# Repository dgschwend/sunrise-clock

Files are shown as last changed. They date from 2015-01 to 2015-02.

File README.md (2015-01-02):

Sunrise Clock
=============

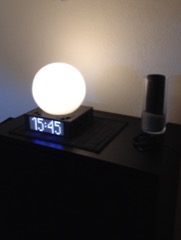
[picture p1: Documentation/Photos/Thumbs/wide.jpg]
Image of Alarm Clock from Wide Angle
[][wide]        
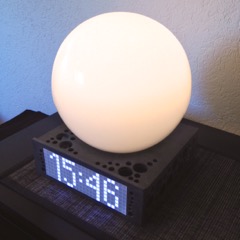
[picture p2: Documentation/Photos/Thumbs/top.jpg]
Image of Top of Alarm Clock
[][top]

A hand-made alarm clock that uses slowly increasing light and sound to wake you up.

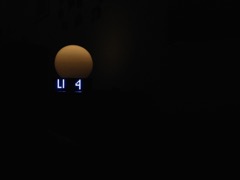
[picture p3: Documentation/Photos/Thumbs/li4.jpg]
[][li4] 
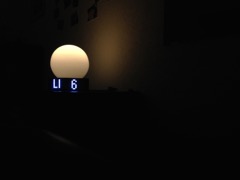
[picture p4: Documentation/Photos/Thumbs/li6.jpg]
[][li6] 
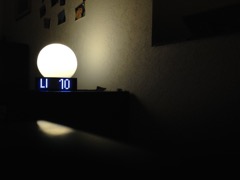
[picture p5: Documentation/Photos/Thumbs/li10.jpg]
Image of Medium Light
[][li10] 
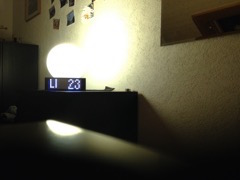
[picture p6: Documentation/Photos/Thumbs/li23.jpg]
Image of Bright Light
[][li23]

## Project Features

Built for an Arduino Pro Mini using the fantastic [Arduino Che Cosa framework](http://github.com/mikaelpatel/Cosa).

  - White LED Matrix Display shows Time and Menus
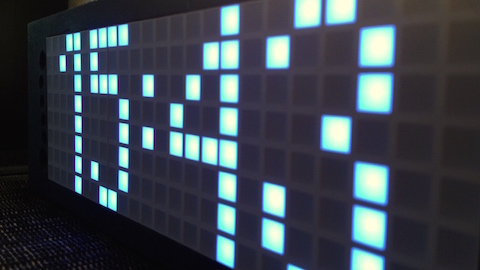
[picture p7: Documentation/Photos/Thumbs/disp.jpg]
Image of Display
   [][disp]    
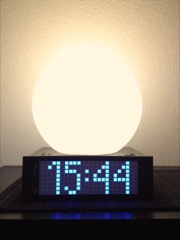
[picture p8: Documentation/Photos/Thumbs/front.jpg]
Image of Front
   [][front]

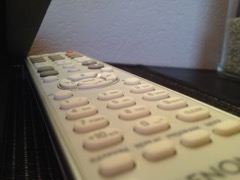
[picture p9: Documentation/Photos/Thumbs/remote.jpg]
Image of IR Remote
  - [][remote]        IR recevier, Apple Remote (or others) for control

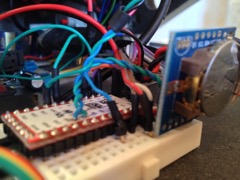
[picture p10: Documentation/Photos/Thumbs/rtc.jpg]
Image of Real-Time Clock
  - [][rtc]        TinyRTC Real-Time Clock (for time and alarms, battery-backup)
  
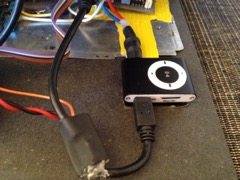
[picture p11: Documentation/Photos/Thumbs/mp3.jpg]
Image of MP3 Player
  - [][mp3]        Cheap chinese MP3 Player for Wakeup Sound

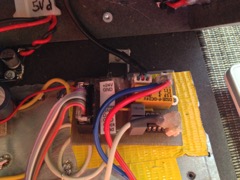
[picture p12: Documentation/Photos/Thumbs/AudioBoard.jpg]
Image of AudioBoard
  - [][AudioBoard]        Audio Volume Control (via LM1972)

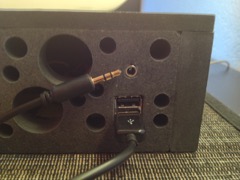
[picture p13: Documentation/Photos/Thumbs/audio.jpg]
Image of Audio AUX Port
  - [][audio]        Audio Switch (external Jack input, internal MP3)

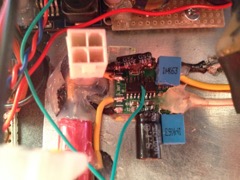
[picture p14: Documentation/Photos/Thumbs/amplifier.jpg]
Image of Amplifier
  - [][amplifier]        2 x 3W Amplifier (PAM8403)

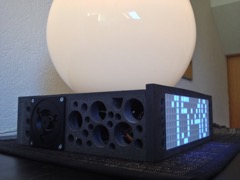
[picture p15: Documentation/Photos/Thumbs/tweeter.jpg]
Image of Tweeter
  - [][tweeter]        2-way Speaker
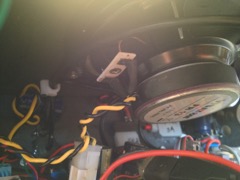
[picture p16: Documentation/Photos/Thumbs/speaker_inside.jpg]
Image of Speaker inside
  - [][speaker_inside]        Subwoofer included in glass sphere
 
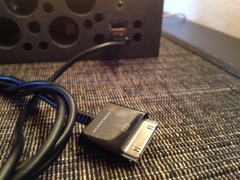
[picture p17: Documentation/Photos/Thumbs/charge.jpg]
Image of Charge Port
  - [][charge]        2x USB Charger 5V @ 1.5A

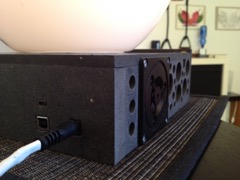
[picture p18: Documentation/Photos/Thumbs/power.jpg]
Image of Power and USB Config Port
  - [][power]        USB Flash / Debug Port <--> FTDI <--> Arduino

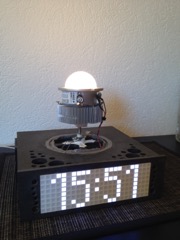
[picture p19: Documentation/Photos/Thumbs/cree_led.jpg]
Image of Cree LMH2 LED
  - [][cree_led]                     Cree LMH2 850-lumen LED with sunset dimming

  - old Apple iBook G4 Power Supply @24.8V, 1.8A for Power

## Under-the-Hood Impressions

### Setup and Cabling
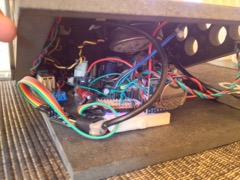
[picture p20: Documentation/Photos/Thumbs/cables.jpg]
Image of Cables
[][cables]
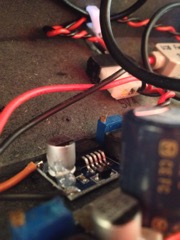
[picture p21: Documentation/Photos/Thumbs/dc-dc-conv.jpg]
Image of DC-DC Converter
[][dc-dc-conv]
[Image of Real-Time Clock][rtc]

DIY PCB for Audio Volume Control. All cabling and setup still in prototype stage. I'm thinking about doing a small PCB for all the components... Audio Quality could certainly be improved with properly shielded 4-layer PCB.

### Audio Hardware
[Image of Amplifier][amplifier]
[Image of AudioBoard][AudioBoard]
[Image of Speaker inside][speaker_inside]
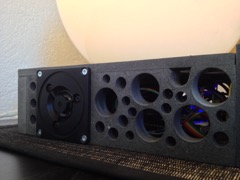
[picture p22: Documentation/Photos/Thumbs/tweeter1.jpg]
Image of Tweeter
[][tweeter1]

Subwoofer Speaker uses the Glass Sphere (from an IKEA Fado Lamp) as Body. Sealing of Glass Sphere using custom Silicone Ring. No apsorptive material in sphere yet... might improve frequency response!

[Image of MP3 Player][mp3]
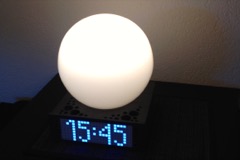
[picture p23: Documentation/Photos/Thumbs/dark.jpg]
Image of Dark State
[][dark]

### Dimming of LED
[Image of Very Low Light][li4]
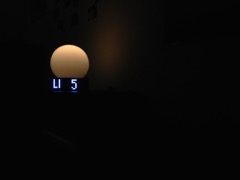
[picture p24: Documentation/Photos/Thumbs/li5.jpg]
[][li5]
[Image of Low Light][li6]
[Image of Medium Light][li10]
[Image of Bright Light][li23]

## More Infos
Star this Project and contact me if you would like to know more. Right now, many parts are not properly documented. If there's any interest, I may draw and publish the full Schematics.

[i_amplifier]: https://raw.githubusercontent.com/dgschwend/sunrise-clock/master/Documentation/Photos/Thumbs/amplifier.jpg
[amplifier]: https://github.com/dgschwend/sunrise-clock/blob/master/Documentation/Photos/amplifier.jpg
[i_audio]: https://raw.githubusercontent.com/dgschwend/sunrise-clock/master/Documentation/Photos/Thumbs/audio.jpg
[audio]: https://github.com/dgschwend/sunrise-clock/blob/master/Documentation/Photos/audio.jpg
[i_AudioBoard]: https://raw.githubusercontent.com/dgschwend/sunrise-clock/master/Documentation/Photos/Thumbs/AudioBoard.jpg
[AudioBoard]: https://github.com/dgschwend/sunrise-clock/blob/master/Documentation/Photos/AudioBoard.jpg
[i_cables]: https://raw.githubusercontent.com/dgschwend/sunrise-clock/master/Documentation/Photos/Thumbs/cables.jpg
[cables]: https://github.com/dgschwend/sunrise-clock/blob/master/Documentation/Photos/cables.jpg
[i_charge]: https://raw.githubusercontent.com/dgschwend/sunrise-clock/master/Documentation/Photos/Thumbs/charge.jpg
[charge]: https://github.com/dgschwend/sunrise-clock/blob/master/Documentation/Photos/charge.jpg
[i_cree_led]: https://raw.githubusercontent.com/dgschwend/sunrise-clock/master/Documentation/Photos/Thumbs/cree_led.jpg
[cree_led]: https://github.com/dgschwend/sunrise-clock/blob/master/Documentation/Photos/cree_led.jpg
[i_dark]: https://raw.githubusercontent.com/dgschwend/sunrise-clock/master/Documentation/Photos/Thumbs/dark.jpg
[dark]: https://github.com/dgschwend/sunrise-clock/blob/master/Documentation/Photos/dark.jpg
[i_dc-dc-conv]: https://raw.githubusercontent.com/dgschwend/sunrise-clock/master/Documentation/Photos/Thumbs/dc-dc-conv.jpg
[dc-dc-conv]: https://github.com/dgschwend/sunrise-clock/blob/master/Documentation/Photos/dc-dc-conv.jpg
[i_disp]: https://raw.githubusercontent.com/dgschwend/sunrise-clock/master/Documentation/Photos/Thumbs/disp.jpg
[disp]: https://github.com/dgschwend/sunrise-clock/blob/master/Documentation/Photos/disp.jpg
[i_front]: https://raw.githubusercontent.com/dgschwend/sunrise-clock/master/Documentation/Photos/Thumbs/front.jpg
[front]: https://github.com/dgschwend/sunrise-clock/blob/master/Documentation/Photos/front.jpg
[i_li4]: https://raw.githubusercontent.com/dgschwend/sunrise-clock/master/Documentation/Photos/Thumbs/li4.jpg
[li4]: https://github.com/dgschwend/sunrise-clock/blob/master/Documentation/Photos/li4.jpg
[i_li5]: https://raw.githubusercontent.com/dgschwend/sunrise-clock/master/Documentation/Photos/Thumbs/li5.jpg
[li5]: https://github.com/dgschwend/sunrise-clock/blob/master/Documentation/Photos/li5.jpg
[i_li6]: https://raw.githubusercontent.com/dgschwend/sunrise-clock/master/Documentation/Photos/Thumbs/li6.jpg
[li6]: https://github.com/dgschwend/sunrise-clock/blob/master/Documentation/Photos/li6.jpg
[i_li10]: https://raw.githubusercontent.com/dgschwend/sunrise-clock/master/Documentation/Photos/Thumbs/li10.jpg
[li10]: https://github.com/dgschwend/sunrise-clock/blob/master/Documentation/Photos/li10.jpg
[i_li23]: https://raw.githubusercontent.com/dgschwend/sunrise-clock/master/Documentation/Photos/Thumbs/li23.jpg
[li23]: https://github.com/dgschwend/sunrise-clock/blob/master/Documentation/Photos/li23.jpg
[i_mp3]: https://raw.githubusercontent.com/dgschwend/sunrise-clock/master/Documentation/Photos/Thumbs/mp3.jpg
[mp3]: https://github.com/dgschwend/sunrise-clock/blob/master/Documentation/Photos/mp3.jpg
[i_power]: https://raw.githubusercontent.com/dgschwend/sunrise-clock/master/Documentation/Photos/Thumbs/power.jpg
[power]: https://github.com/dgschwend/sunrise-clock/blob/master/Documentation/Photos/power.jpg
[i_remote]: https://raw.githubusercontent.com/dgschwend/sunrise-clock/master/Documentation/Photos/Thumbs/remote.jpg
[remote]: https://github.com/dgschwend/sunrise-clock/blob/master/Documentation/Photos/remote.jpg
[i_rtc]: https://raw.githubusercontent.com/dgschwend/sunrise-clock/master/Documentation/Photos/Thumbs/rtc.jpg
[rtc]: https://github.com/dgschwend/sunrise-clock/blob/master/Documentation/Photos/rtc.jpg
[i_speaker_inside]: https://raw.githubusercontent.com/dgschwend/sunrise-clock/master/Documentation/Photos/Thumbs/speaker_inside.jpg
[speaker_inside]: https://github.com/dgschwend/sunrise-clock/blob/master/Documentation/Photos/speaker_inside.jpg
[i_top]: https://raw.githubusercontent.com/dgschwend/sunrise-clock/master/Documentation/Photos/Thumbs/top.jpg
[top]: https://github.com/dgschwend/sunrise-clock/blob/master/Documentation/Photos/top.jpg
[i_tweeter]: https://raw.githubusercontent.com/dgschwend/sunrise-clock/master/Documentation/Photos/Thumbs/tweeter.jpg
[tweeter]: https://github.com/dgschwend/sunrise-clock/blob/master/Documentation/Photos/tweeter.jpg
[i_tweeter1]: https://raw.githubusercontent.com/dgschwend/sunrise-clock/master/Documentation/Photos/Thumbs/tweeter1.jpg
[tweeter1]: https://github.com/dgschwend/sunrise-clock/blob/master/Documentation/Photos/tweeter1.jpg
[i_wide]: https://raw.githubusercontent.com/dgschwend/sunrise-clock/master/Documentation/Photos/Thumbs/wide.jpg
[wide]: https://github.com/dgschwend/sunrise-clock/blob/master/Documentation/Photos/wide.jpg

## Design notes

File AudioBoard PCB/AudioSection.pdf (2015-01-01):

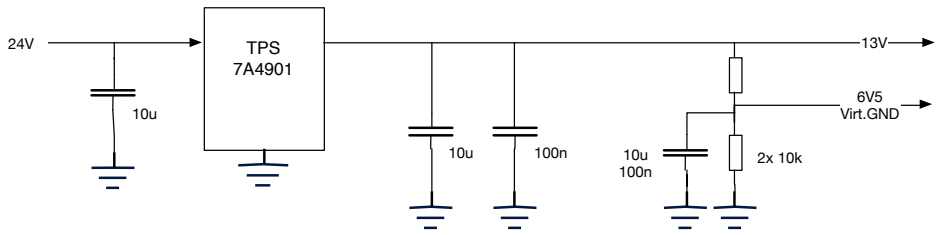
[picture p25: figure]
TPS 7A4901; 6V5 Virt.GND

LM 2596 Module
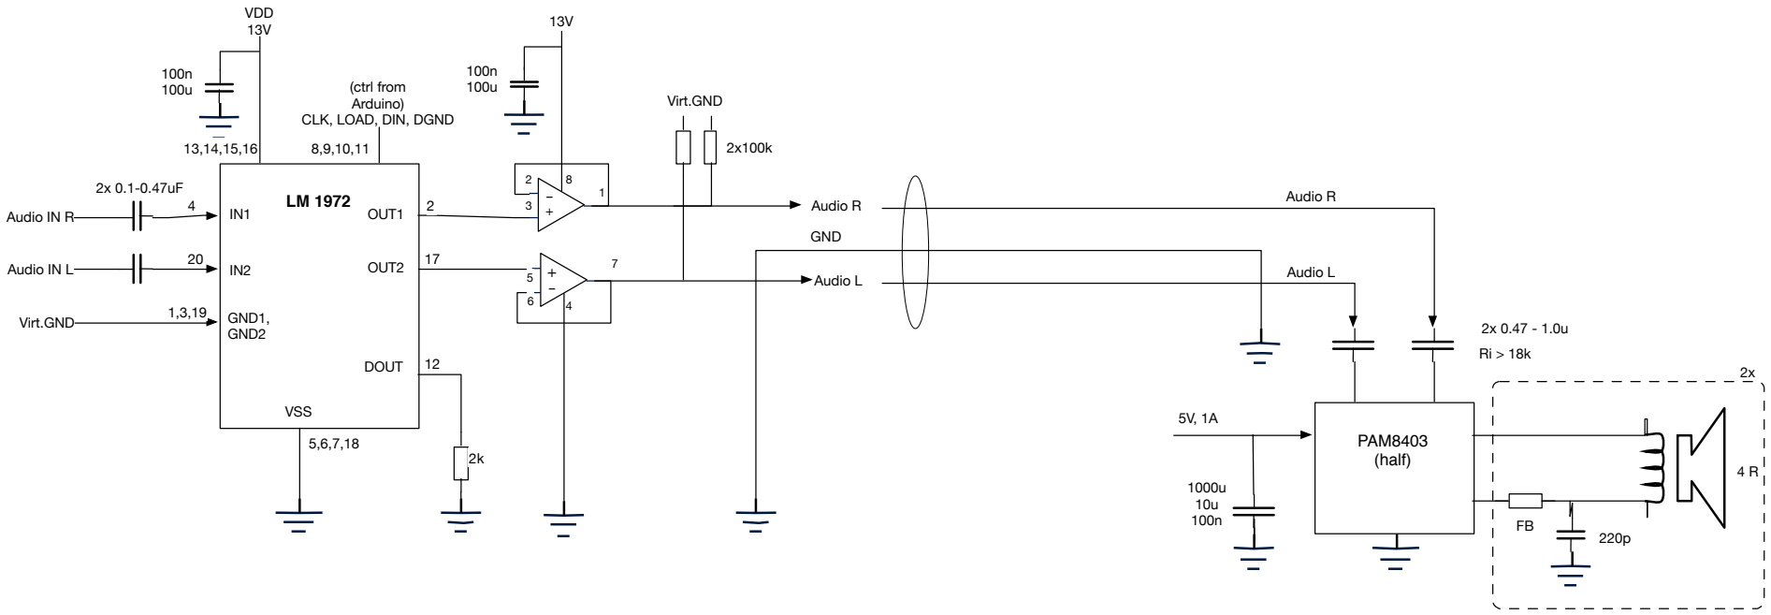
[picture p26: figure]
PAM8403 (half); Audio R; LM 1972 Audio IN R; VDD 13V; Audio IN L; GND1, GND2; Virt.GND; (ctrl from Arduino) CLK, LOAD, DIN, DGND; OUT1; OUT2; DOUT; VSS; Audio L; GND

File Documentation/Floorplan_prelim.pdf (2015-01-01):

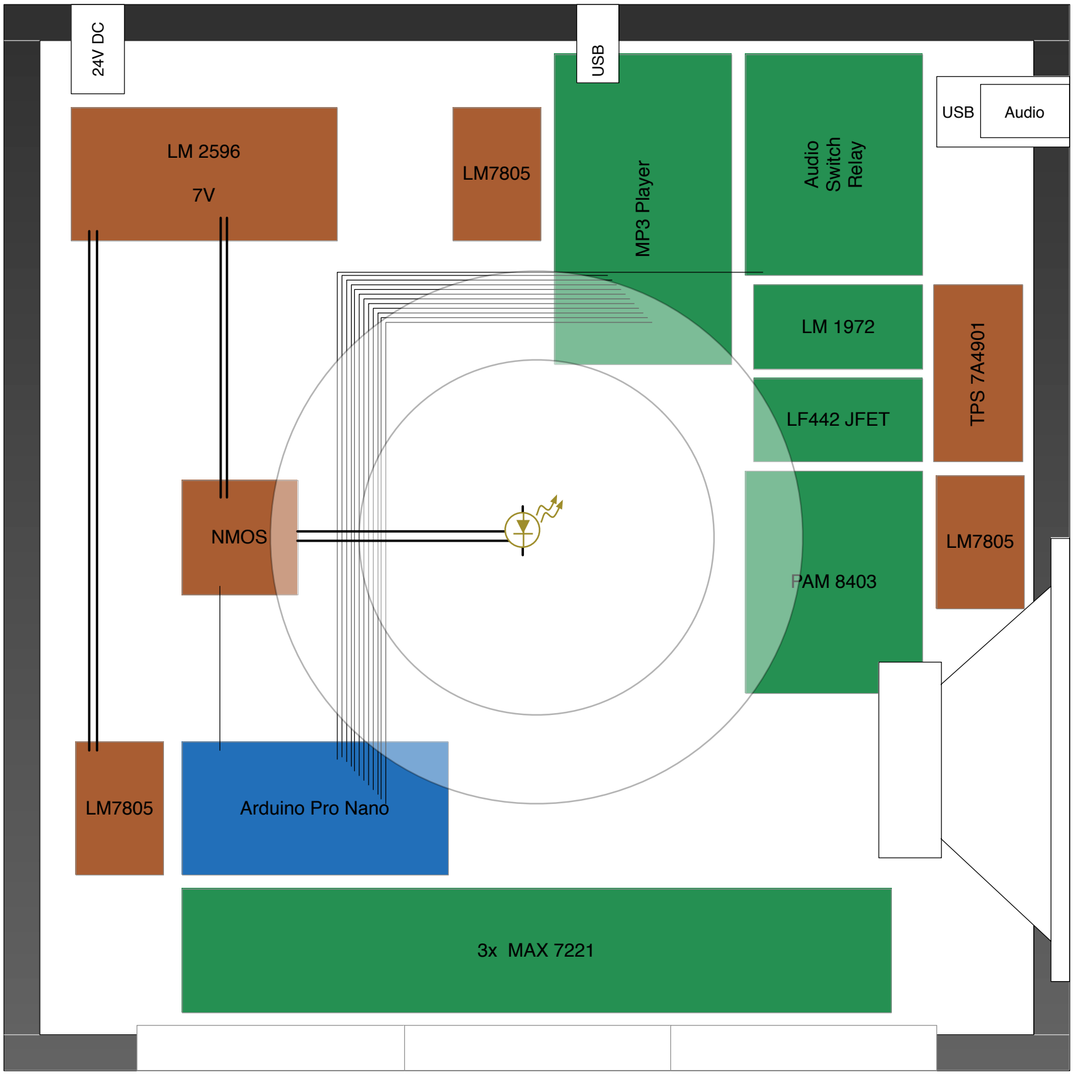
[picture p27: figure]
3x MAX 7221; NMOS; Arduino Pro Nano; USB; Audio; TPS 7A4901; Switch; Relay; MP3 Player; PAM 8403; LF442 JFET

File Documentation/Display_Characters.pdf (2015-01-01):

. | . | . | . | . | r | . | . | . | .
. | . | . | . | . | . | . | . | . | r | . | . | . | . | .
. | . | . | . | . | r | . | . | .
. | . | . | . | . | r | . | . | .
. | . | h | | | h | h | h | h
. | . | h | h | h | h
. | . | h | h | h | h
. | . | h | h | h | h | h | h | h
. | . | h | h | h | h
. | . | h | h | h | h
. | . | h | h | h | h

# Change Volume

# Uhrzeit (Volume: 4) Click

# Sound Level

# Menu Item

# New Volume: 5 MENU

+

–

" #$ !

# Hold

# New Volume: 6 … Hold …

# Maximum Volume

# Volume in- / decreases at KeyRepetitionRate

# Immediate Mute

# Uhrzeit (Volume: X)

# Fast Double-Click

# (dt < KeyRepetitionRate)

# Volume immediately set to 0

# Change Light Level (Dimming)

# Uhrzeit (Light Level: 2)

# Click

# New Light Level: 3

# Alternative Symbol Sound

# Alternative Symbols Licht

. | . | . | . | . | 1 | 1 | . | .
. | . | . | . | . | 1 | 1 | . | .
. | . | . | . | . | 1 | . | .
. | . | . | . | . | 1 | . | .
. | . | . | . | . | 1 | . | .
. | . | . | . | . | 1 | . | ..
. | . | . | . | . | . | 11 | . | .

# Alternative Symbol Sound

# Hold

# New Light Level: 4 … Hold …

# Maximum Light Level

# Light Level in- / decreases at KeyRepetitionRate

# Alternative Symbol Sound

# MENU

+

–

" #$ !

# MENU

–

" #$ !
–

# MENU

+

–

" #$ !

# MENU

+

–

" #$ !

# Immediate Full Light

# Uhrzeit (Light Level: 2) Fast Double-Click

# (dt < KeyRepetitionRate)

# New Light Level: 3

# MENU

+

–

! " #$ !

# Show Time

# Uhrzeit (Light Level: 2)

# no input for IdleTimeout seconds

# New Light Level: 3

. | . | . | . | . | . | . | . | . | x | x
. | . | . | . | . | . | x | x
. | . | . | . | . | . | x | x
. | . | . | . | . | . | . | x
. | . | . | . | . | . | x | x
. | . | . | . | . | . | x | x
. | . | . | . | . | . | . | . | x | x

# Set Alarm

# Uhrzeit (Light Level: 2) Click

. | . | . | . | . | r | . | . | . | .
. | . | . | . | . | . | . | . | . | r | . | . | . | . | .
. | . | . | . | . | r | . | . | .
. | . | . | . | . | r | . | . | .

# New Light Level: 3 MENU

+

–

" #$ !

x | x | 1 | 1 | 1 | 1 | 1 | 1 | 1 | 1 | 1 | 1 | 1 | 1 | 1 | 1 | 1 | 1 | 1 | y | y | 1 | 1 | 1
x | x | 1 | 1 | 1 | 1 | 1 | 1 | 1 | 1 | 1 | 1 | y | y | 1
x | x | 1 | 1 | 1 | 1 | 1 | 1 | 1 | 1 | 1 | 1 | 1 | y | 1
x | 1 | 1 | 1 | 1 | 1 | 1 | 1 | 1 | 1 | 1 | 1 | 1 | 1 | 1
1 | 1 | 1 | 1 | 1 | 1 | 1 | 1 | 1 | 1 | 1 | 1
1 | 1 | 1 | 1 | 1 | 1 | 1 | 1 | 1 | 1 | 11 | 1
x | x | 1 | 1 | 1 | 1 | 1 | 1 | 1 | 1 | 1 | 1 | 1 | 1 | 1 | 1 | 1 | 1 | 1 | 1 | y | 1 | 1 | 11
| 2 . | | . | . | . | . | . | .
2 | . | . | . | . | . | . | .
2 | . | . | . | 2 | . | . | .
2 | 2 | . | 2 | 2 | . | .
2 | 2 | . | . | 2 | . | . | .
2 | . | . | . | . | . | .
2 | 2 | 2 . | . | . | . | . | . | .

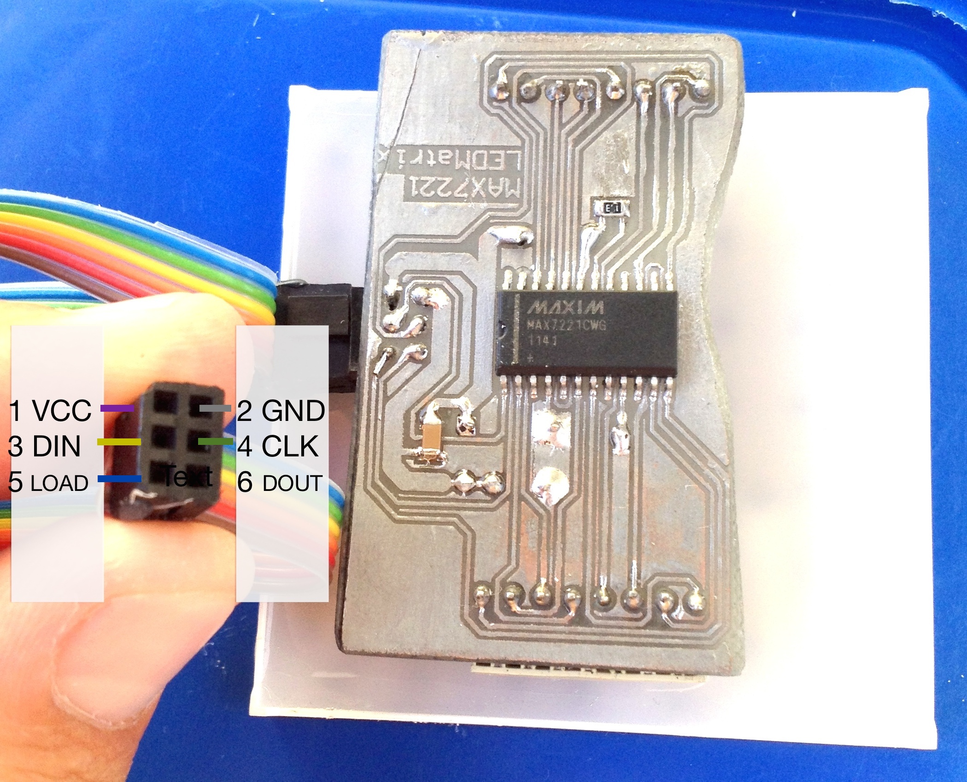
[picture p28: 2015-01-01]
Documentation/MAX7221 Module Pinout.jpg

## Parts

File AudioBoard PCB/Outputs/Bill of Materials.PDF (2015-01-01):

Component list | <Parameter Title not found>
Source Data From: | audioboard.PrjPcb
| Project: | | | | | | audioboard.PrjPcb
| Variant: | | | | | | None
| Report Date: | | | | | 7/3/2014 | 2:17:10 PM
| Print Date: | | | | | 03-Jul-14 | 2:17:18 PM
# | Category | Designator | Description | Comment | Package / Case | Footprint | Manufacturer | Manufacturer Part Number | Supplier Part Number 1 | Quantity

1 | Capacitors | C1, C5 | CAP CER 10NF 50V 10% X7R 1206 | 10n | 1206 (3216 Metric) | CAPC3216X17N | Yageo | CC1206KRX7R9BB103 | 311-1174-1-ND | 2
2 | Capacitors | C2, C3, C4 | CAP CER 100NF 50V 10% X7R 1206 | 10u | 1206 (3216 Metric) | CAPC3216X17N | Kemet | C1206C104K5RACTU | | 3
3 | Capacitors | C6, C7 | CAP ALUM 1000UF 16V 20% RADIAL | 1000u | Radial, Can | Radial_0254_0381X
| | | | | | 0900 | Panasonic Electronic Components | ECA-1CM102B | | 2
4 | | D1 | 275 Amp Avg Pow er Silicon Rectifier Diode | 1N4048 | | DO-35 | | | | 1
5 | Relays | K1 | Relay 24V | DS2E-F-24V | | DS2E-F-DC24V | Panasonic Electric Works | DS2E-S-DC24V | | 1
6 | | Q1 | HEXFET N-Channel Pow er MOSFET | IRF730 | | TO-220AB | | | | 1
7 | Resistors | R1, R2, R4 | RES 10K OHM 1/8W 1% 0805 SMD | 10K | 0805 (2012 Metric) | RESC2012X06M | Yageo | RC0805FR-0710KL | | 3
8 | Resistors | R3 | RES 1.00K OHM 1/4W 1% 1206 SMD | 1K | 1206 (3216 Metric) | RESC3216X07N | Yageo | RC1206FR-071KL | 311-1.00KFRCT-ND | 1
9 | Resistors | R5 | RES 2.20K OHM 1/8W 1% 0805 SMD | 2K2 | 0805 (2012 Metric) | RESC2012X06N | Yageo | RC0805FR-072K2L | | 1
10 | Integrated Circuits (ICs) | U1 | IC, ADJ LDO REG, 1.2V-33V, 0.15A, MSOP-8 | TPS7A4901 | 8-TSSOP, 8-MSOP (0.118", 3.00mm Width) Exposed Pad | MSOP-8 | Texas Instruments | TPS7A4901DGNR | 296-27751-2-ND | 1
11 | U2 | LM1972 | SOIC- 20_0127_7.5mm
1
12 | U3 | LF442 Dual Low Pow er JFET Input
Operational Amplifier
| | LF442CN | DIP- 08_0254_0762_042
| | | 0
TEXAS INSTRUMENTS | LF442CN | 1
13 | Connectors,
Interconnects
X1 | Stecker 2-Pin | 24V IN | CON_1X02S_0254 | Sullins Connector Solutions | PREC040SFAN-RC | 1
14 | Connectors,
Interconnects
X2 | Stecker 3-Pin | Audio Out | CON_1X03S_0254 | Sullins Connector Solutions | PREC040SFAN-RC | 1
15 | Connectors,
Interconnects
X3 | Stecker 3-Pin | Audio IN1 | CON_1X03S_0254 | Sullins Connector Solutions | PREC040SFAN-RC | 1
16 | Connectors,
Interconnects
X4 | Stecker 3-Pin | Audio IN2 | CON_1X03S_0254 | Sullins Connector Solutions | PREC040SFAN-RC | 1
17 | Connectors,
Interconnects
X5 | Stecker 4-Pin | Control (Arduino) | CON_1X06S_0254 | Sullins Connector Solutions | PREC040SFAN-RC | 1
Approved | Notes | 23

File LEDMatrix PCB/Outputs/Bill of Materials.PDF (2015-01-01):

Comment | Description | Designator | Footprint | LibRef | Quantity
| Capacitor
| (Semiconductor SIM
| Model) | C1 | C1206 | Cap Semi | 1
| Capacitor | C2 | CAPR5-4X5 | Cap2 | 1
LEDMatrix | LED Matrix 8x8 white | M1 | LEDMATRIX | LEDMatrix | 1
Conn | Header, 3-Pin, Dual
| row, Right Angle | P1 | HDR2X3H | Header 3X2H | 1
R set | Resistor | R1 | RESC2012N | Res3 | 1
MAX7221EWG | Serially Interfaced, 8-DU1 | WSO24_N | MAX7221EWG | 1

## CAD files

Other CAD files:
Documentation/CAD_3D_Model.skp

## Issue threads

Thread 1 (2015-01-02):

Add absorptive material into Glass Sphere

dgschwend, 2015-01-02:
- Check Frequency Response before and After
- Check Bass Resonances

dgschwend, 2015-01-11:
[ ] find suitable material: glass wool, loudspeaker wool?
[ ] measure frequency sweep before
[ ] measure frequency sweep after

dgschwend, 2015-01-13:
Frequency Response Measurements done, with and without some smelly old loudspeaker absorption wool. Improvements are minimal, light is not as beautiful with with wool inside. Glass sphere has strong strong absorption around 800 Hz - 1.5 kHz, this is not helped with. Sound reproduction not quite satisfactory for Hi-Fi but for waking up - eeeh, long good enough! :stuck_out_tongue:

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

Closed 2015-01-13.

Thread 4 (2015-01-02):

Lower Brightness of LED Matrix

dgschwend, 2015-01-02:
Change brightness settings resistor.
Originally: 10k (40mA)
Now: 22k (20mA)
New: 50k or higher (>10mA).
Minimum current with 1/32 duty cycle is then only 0.3mA, should no longer be too bright, even in dark room.

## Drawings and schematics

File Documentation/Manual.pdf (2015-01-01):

# SunRise Clock How-To

### SunRise Clock 1.0 How-To

### Dear User

Welcome to the new way of starting your day: Wake up when the first rays of dazzling sunlight break through the forest’s green leaves, sparking new life everywhere and smoothly waking up the deep energy of mother nature. Or maybe let your mind slowly drift out of sleep to the never ending sound of rolling ocean waves and the first sparkling rays reflecting on its bright blue surface. Forget about buzzing alarm clocks abruptly jerking you into a dark, cold world. Your new mornings will be bright and full of energy!

The Dev

### SunRise Clock 1.0 How-To

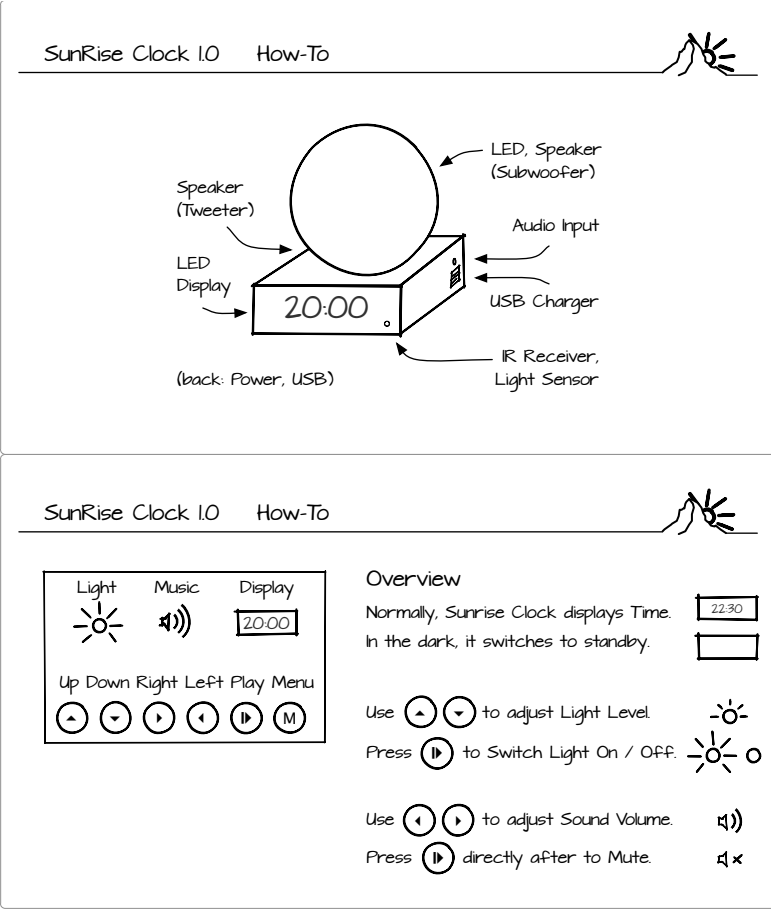
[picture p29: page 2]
SunRise Clock 1.0; How-To; LED, Speaker (Subwoofer); USB Charger; Audio Input; Speaker (Tweeter); LED Display; IR Receiver, Light Sensor; Light; Music; Display; Normally, Sunrise Clock displays Time.; Use; to adjust Sound Volume. $; Press; to Switch Light On / Off. ⏏; to adjust Light Level.; directly after to Mute. ⏏

(back: Power, USB)

Overview
In the dark, it switches to standby.

Up Down Right Left Play Menu

### Setting an Alarm

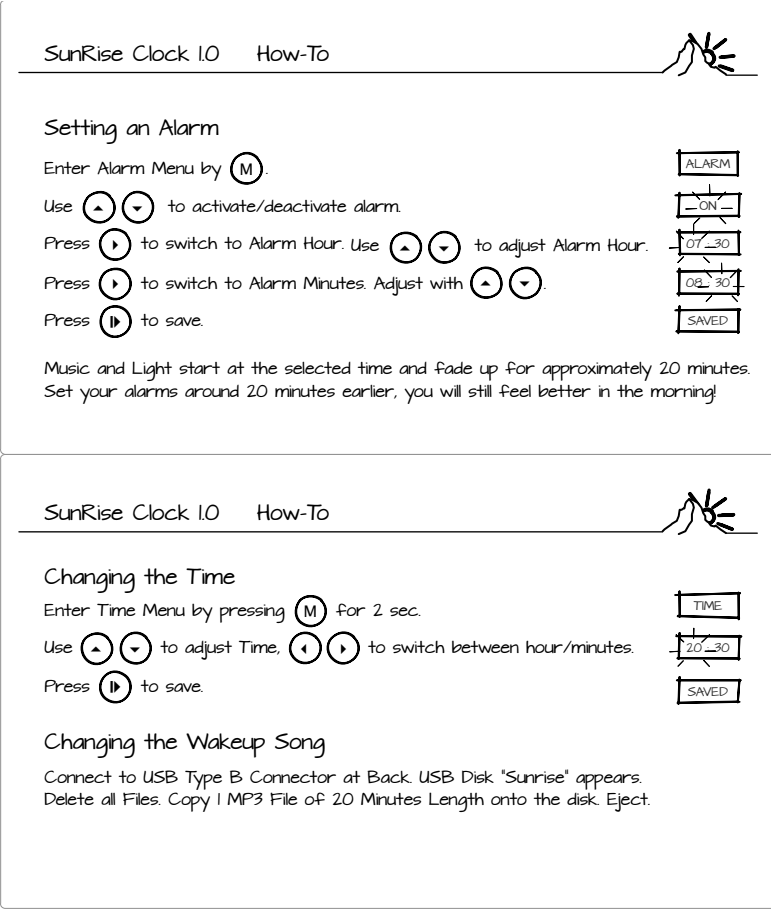
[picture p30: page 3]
SunRise Clock 1.0; How-To; Enter Time Menu by pressing; for 2 sec. M; TIME; Use; to adjust Time,; to switch between hour/minutes. "; Press; to save.; SAVED; Enter Alarm Menu by; ALARM; to activate/deactivate alarm. "; to switch to Alarm Hour. !; to adjust Alarm Hour. "; to switch to Alarm Minutes. Adjust with; SAVED ⏏

Music and Light start at the selected time and fade up for approximately 20 minutes.
Set your alarms around 20 minutes earlier, you will still feel better in the morning!

Changing the Time
Changing the Wakeup Song
Connect to USB Type B Connector at Back. USB Disk “Sunrise” appears.
Delete all Files. Copy 1 MP3 File of 20 Minutes Length onto the disk. Eject.

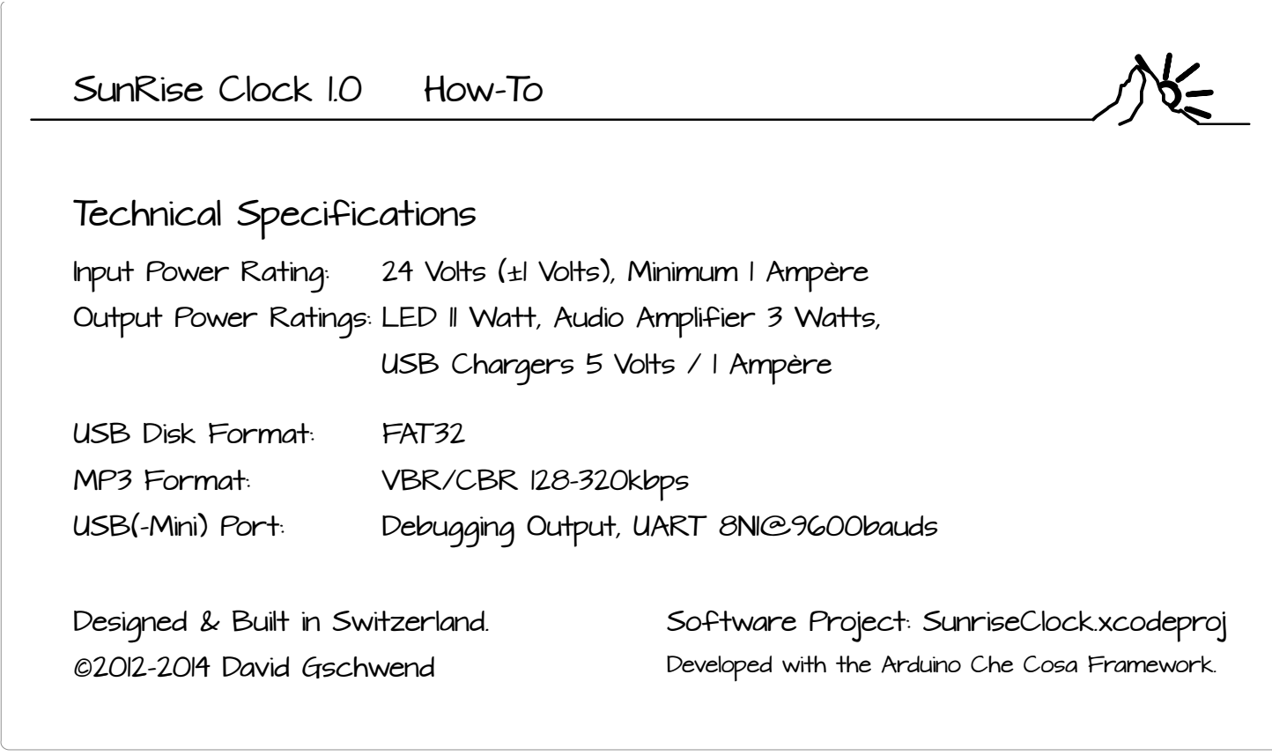
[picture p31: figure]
Technical Specifications; USB Chargers 5 Volts / 1 Ampère; USB Disk Format:; FAT32; MP3 Format:; VBR/CBR 128-320kbps; USB(-Mini) Port:; Debugging Output, UART 8N1@9600bauds; Designed & Built in Switzerland. ©2012-2014 David Gschwend; Software Project: SunriseClock.xcodeproj

Input Power Rating: 24 Volts (±1 Volts), Minimum 1 Ampère Output Power Ratings: LED 11 Watt, Audio Amplifier 3 Watts,

Developed with the Arduino Che Cosa Framework.

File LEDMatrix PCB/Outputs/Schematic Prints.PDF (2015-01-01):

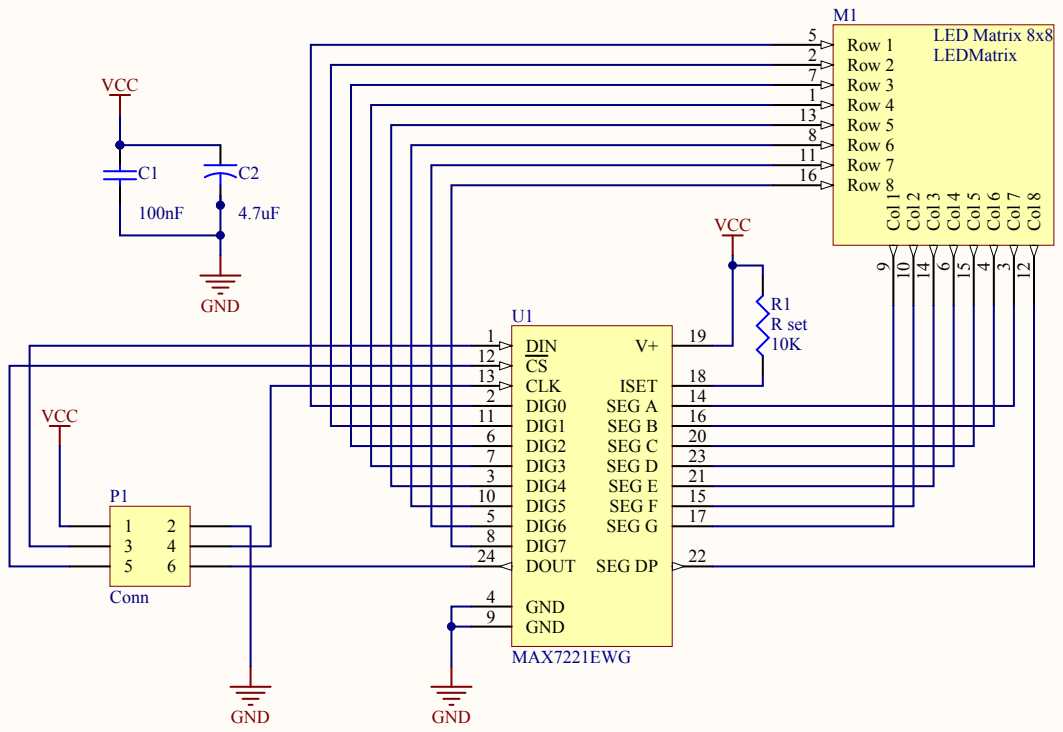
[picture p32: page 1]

Row 5 13
Row 7 11

R set 10K

SEG G DIG1 11 | 17 ISET 18

6 | SEG C DIG2 | 20
3 7 | SEG D DIG3 | 23
SEG E DIG4 | 21
DIG5 10 SEG F | 15

8 | DIG7

5 6 | | | DOUT 24 GND GND

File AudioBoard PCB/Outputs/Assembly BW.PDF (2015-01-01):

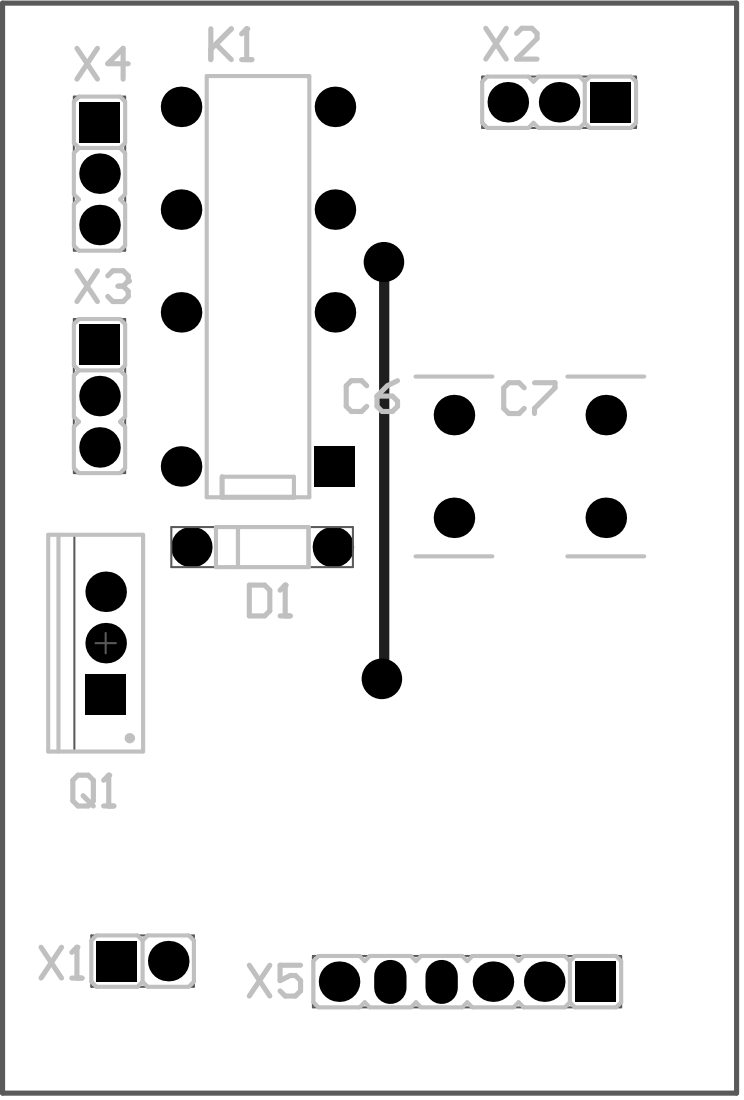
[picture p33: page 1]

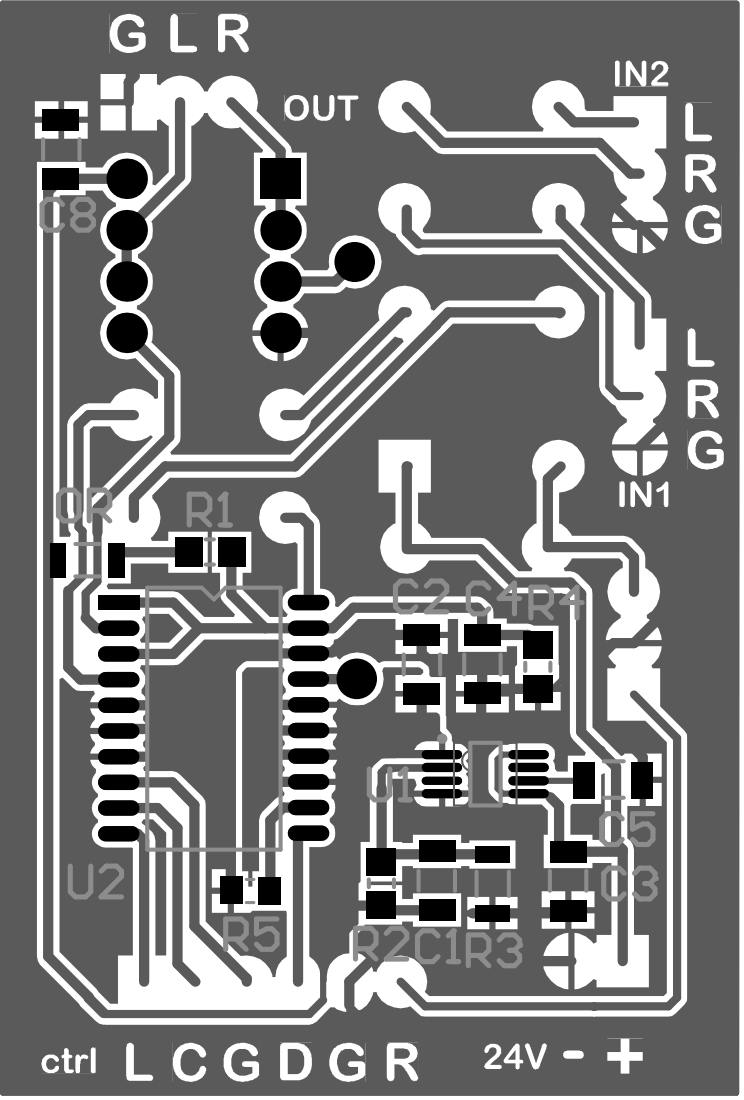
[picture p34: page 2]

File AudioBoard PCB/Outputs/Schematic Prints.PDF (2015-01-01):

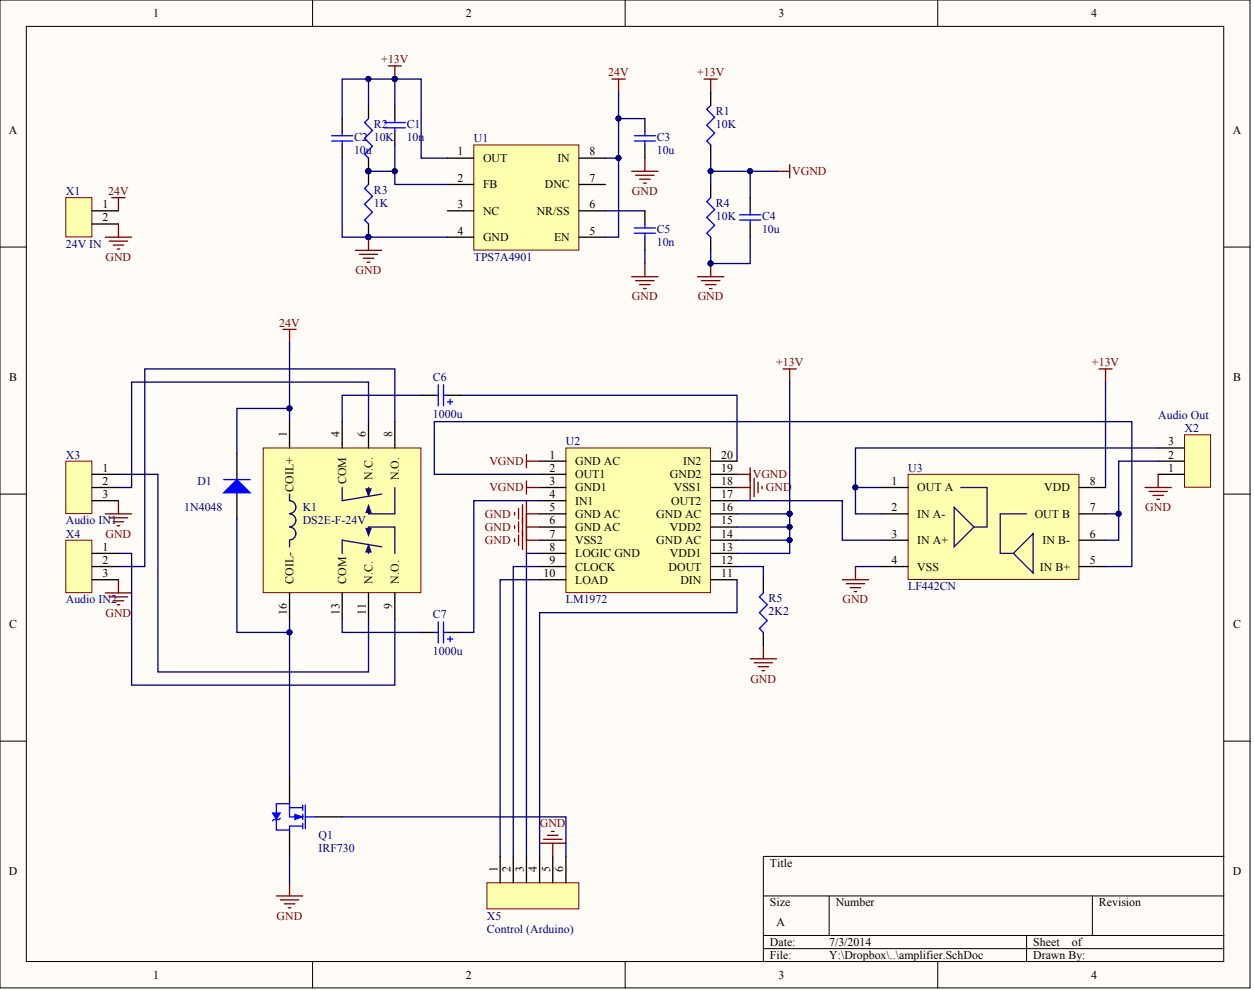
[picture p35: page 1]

LOAD 10

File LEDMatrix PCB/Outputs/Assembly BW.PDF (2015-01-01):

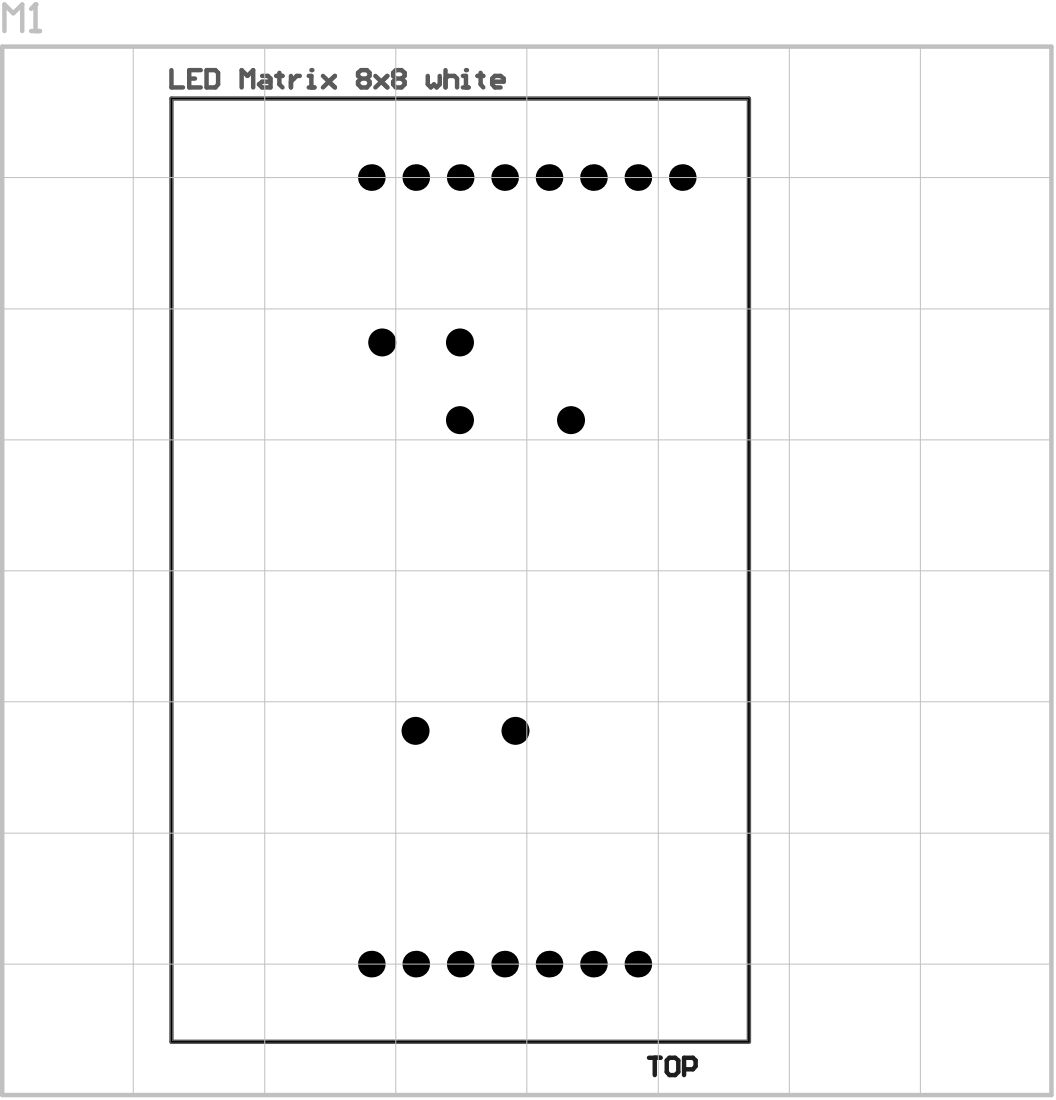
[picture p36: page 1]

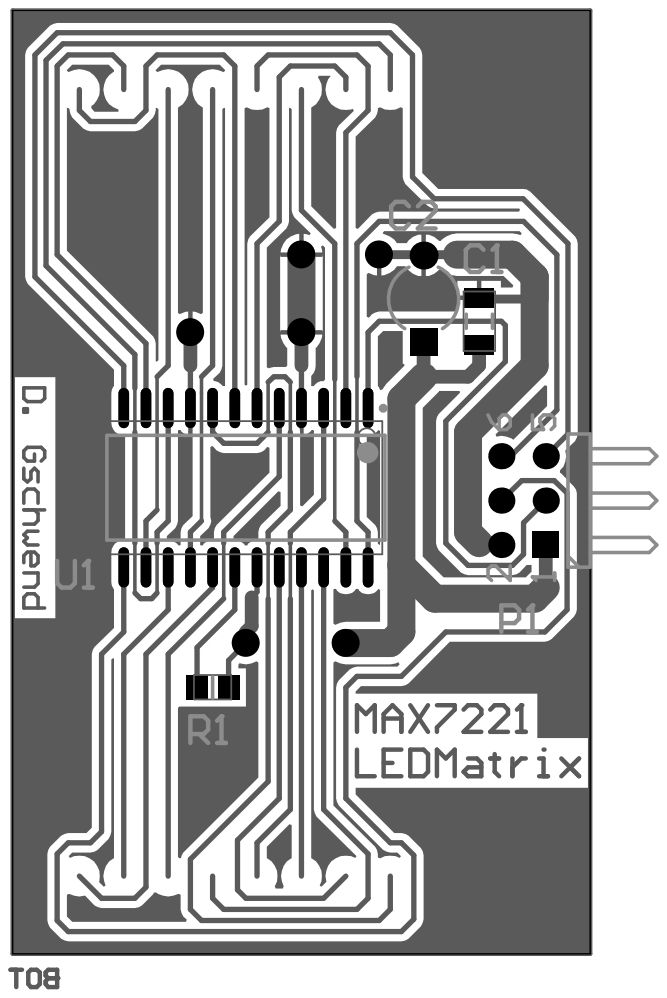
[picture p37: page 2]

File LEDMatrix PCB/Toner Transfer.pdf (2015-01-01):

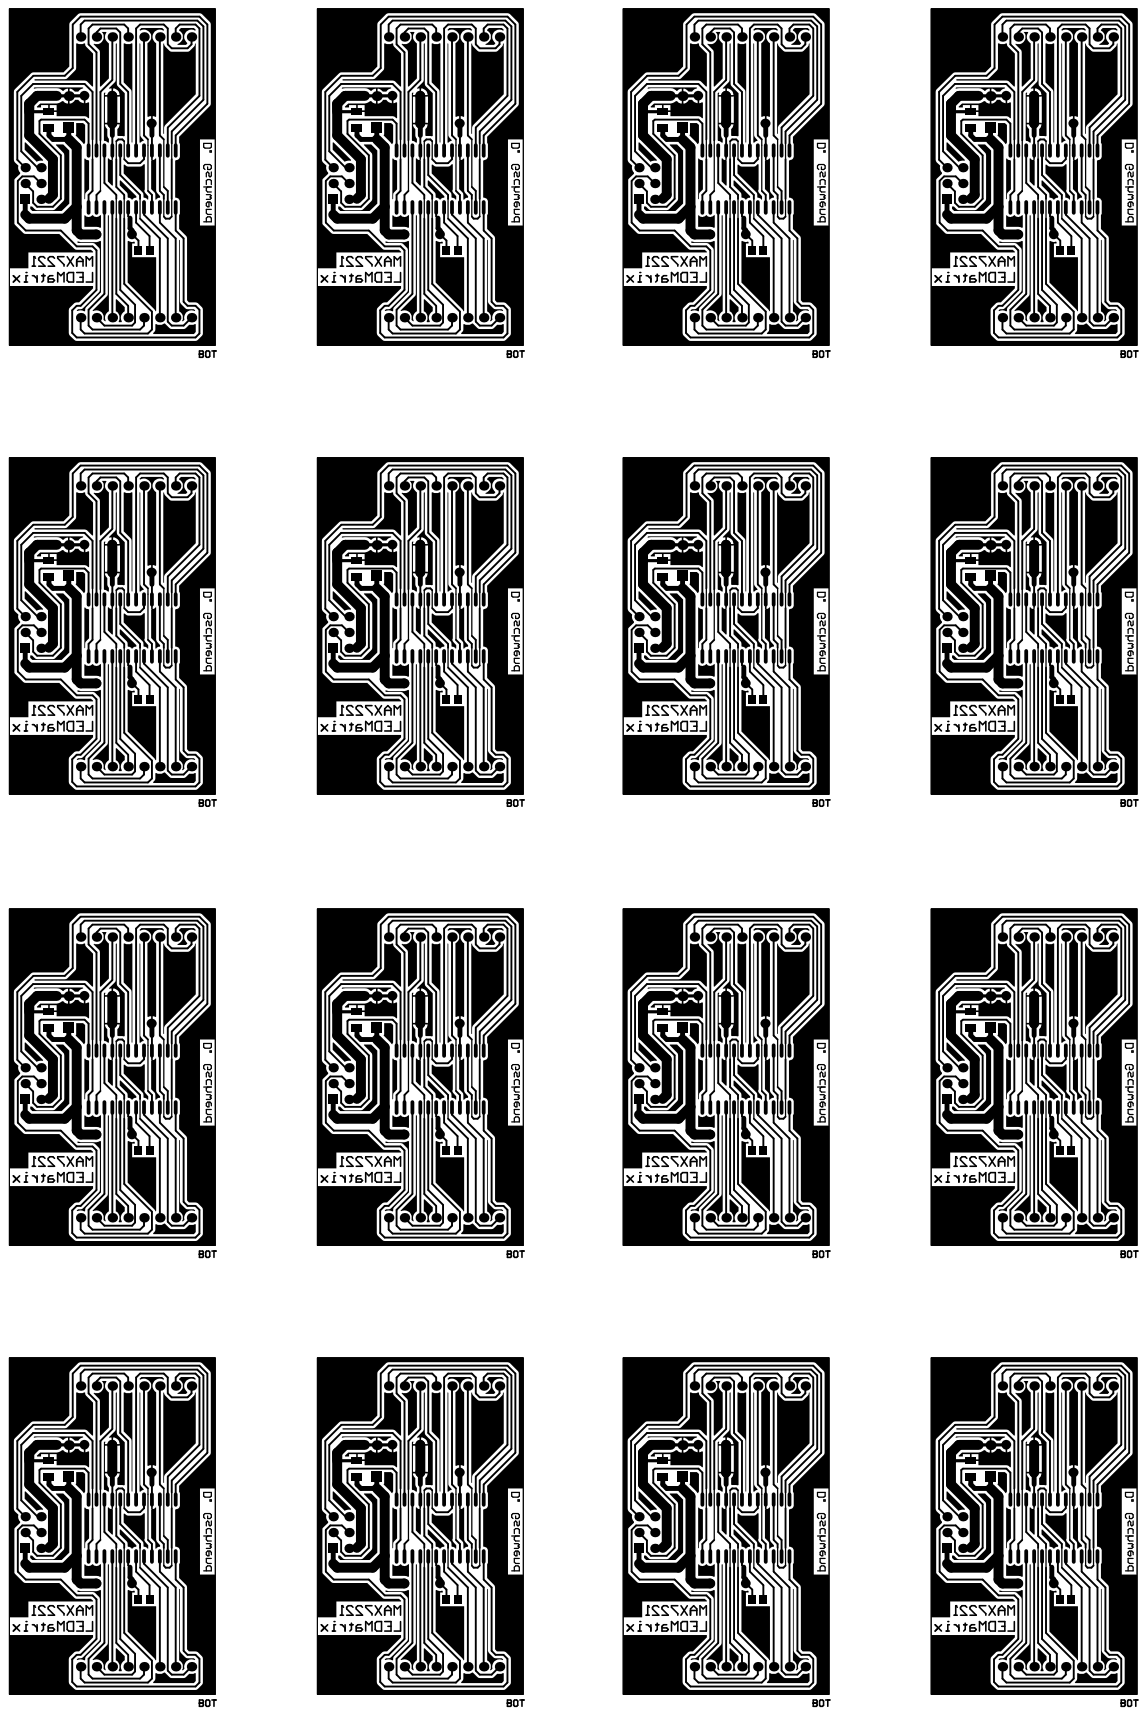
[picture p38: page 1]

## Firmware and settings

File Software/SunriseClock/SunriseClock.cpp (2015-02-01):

///
/// @mainpage	SunriseClock
/// @details	SunriseClock Software
///
/// @file		SunriseClock.cpp
/// @brief		Main sketch
///
/// @n @a		Developed with [embedXcode+](http://embedXcode.weebly.com)
///
/// @author		David Gschwend
/// @date		28.08.14 20:19
///
/// @copyright	(c) David Gschwend, 2014
/// @copyright	All rights reserved
/// @n
///

/**
 *                       (to FTDI)
 *                      D T R V G G
 *                      |         |
 *                   +---------------+
 *                   |  o o o o o o  |
 *                   | o RAW    TX o |
 *                   | o GND    RX o |
 *                   | o RST   RST o |
 *          +5V      | o VCC*  GND o |    GND
 *                   | o A3 *    2 o |    IR Receiver (IRQ INT0)
 *                   | o A2      3 o |    Light (PWM)
 *                   | o A1      4 o |    LCD SDIN (violet)
 *                   | o A0      5 o |    LCD SCLK
 *  (onboard LED)    | o 13 *    6 o |    LCD SCE  (blue)
 *  Volume load      | o 12 *    7 o |    MP3 Power
 *  Volume clk       | o 11      8 o |    Sound Source Relay
 *  Volume din       | o 10      9 o |    Amplifier Mute
 *                   +---------------+
 *
 *                         * (A4) SDA     RTC I2C Data
 *                         * (A5) SCL     RTC I2C Clock
 *                         * (A6) ADC6    LUX Monitor
 *                         * (A7) ADC7    RTC I2C Clock
 **/

// Include core libraries
#include "Cosa/Board.hh"
#include "Cosa/Board/Arduino/Pro_Mini.hh"
#include "Cosa/OutputPin.hh"
#include "Cosa/AnalogPin.hh"
#include "Cosa/Watchdog.hh"
#include "Cosa/Event.hh"

#include "Cosa/RTC.hh"
#include "Cosa/Power.hh"
#include "Cosa/Watchdog.hh"
#include "Cosa/InputPin.hh"
#include "Cosa/IOStream/Driver/UART.hh"
#include "Cosa/TWI/Driver/DS1307.hh"

#include "StateController.h"
#include "SystemStates.h"
#include "SoundController.h"
#include "MAX7221.h"
#include "LuxMonitor.h"
#include "IRMonitor.h"
#include "TimeKeeper.h"
#include "MP3Controller.h"
#include "TouchMonitor.h"

StateController system(&i_StartupState);

/// @brief  Initialize Sound Controller
/// din      LM1972 Data IN         D10
/// clk      LM1972 Clock signal    D11
/// load     LM1972 Load signal     D12
/// mute     PAM8403 Mute signal    D9
/// relay    Source Switch Relay    D8
/// mp3power MP3 Player Power FET   D7
//
SoundController sound_ctrl(Board::D10, Board::D11, Board::D12, Board::D9, Board::D8, Board::D7);

/// @brief  Initialize Light Controller Driver
/// @param  ledPin  Pin to LED control FET  PWM0 = D3
///
LightController  light_ctrl(Board::PWM0);

// MAX7221 LED Display on Pins  D4-D6
// sdin screen data pin         D4 (violet)
// sclk screen clock pin        D5
// sce  screen chip enable pin  D6 (blue)
LCD::Serial3W   lcd_io(Board::D4, Board::D5, Board::D6);
MAX7221         lcd_ctrl(&lcd_io);
IOStream        lcd(&lcd_ctrl);

// OPT101 Photodiode (blue) on Pin A0
// Change brightness by (new-old)/filterTau every 128ms
LuxMonitor lux_monitor(Board::A0, &lcd_ctrl, 32);

// IR Receiver (green) on Pin D2 (EXT0)
// Monitor IR receiver for 32bit packets (48b for Denon Remote), with threshold of 1500us
IRMonitor  ir_monitor(Board::EXT0, &system, 32, 1500);

// DS1307 Real-Time Clock
// Attached to I2C bus, Pins A4 (SDA) & A5 (SCL)
TimeKeeper time_keeper;

// Capacitive Touch Pins
// Connect Pin to Copper Pad and to VCC by 1 MOhm resistor.
// touchLightUp    "Light +" Button   D14
// touchLightDown  "Light -" Button   D15
// touchVolumeUp   "Volume +" Button  D16
// touchVolumeDown "Volume -" Button  D17
//TouchMonitor touch_monitor(Board::D14, Board::D15, Board::D16, Board::D17);

OutputPin led(Board::LED, 0);

IOStream cout(&uart);

void uart_welcome_message();

void setup()
{
    
    RTC::begin();
    Watchdog::begin(16, Watchdog::push_timeout_events);
    
    uart.begin(9600);
    cout << PSTR("UART started") << endl;

    trace.begin(&uart);
    cout << PSTR("Trace started") << endl;

    sound_ctrl.setVolume(0);
    sound_ctrl.stopMP3();
    cout << PSTR("Sound Control started") << endl;
    
    lcd_ctrl.begin();
    cout << PSTR("LCD started") << endl;

    lux_monitor.begin();
    cout << PSTR("Lux Monitor started") << endl;
    
    ir_monitor.reset();
    cout << PSTR("IR Monitor reset and ready.") << endl;
    
    cout << PSTR("TimeKeeper started.") << endl;
    
    light_ctrl.setLevel(255);
    delay(1000);
    light_ctrl.setLevel(0);
    cout << PSTR("LightController started.") << endl;
    
    system.begin();
    cout << PSTR("StateController begin") << endl;
    
    uart_welcome_message();
    cout << PSTR("System Ready!") << endl;
}

void loop()
{
    // Wait for events (low power mode)
    Event event;
    Event::queue.await(&event);
    event.dispatch();
    
    //led.toggle();
    
    // Handle UART Keyboard Input
    if (uart.available()) {
        char c = uart.getchar();
        if (c == 13)  // Enter / PLAY
            system.onIRMessage(SystemState::PLAY);
        if (c == 'w') // UP
            system.onIRMessage(SystemState::UP);
        if (c == 's') // DOWN
            system.onIRMessage(SystemState::DOWN);
        if (c == 'a') // LEFT
            system.onIRMessage(SystemState::LEFT);
        if (c == 'd') // RIGHT
            system.onIRMessage(SystemState::RIGHT);
        if (c == 'm') // MENU
            system.onIRMessage(SystemState::MENU);
        
        if (c == 't') // Test Alarm
            system.change_state(&i_AlarmState);
    }
  
}

void uart_welcome_message() {
    cout << PSTR("            .-'`'-.") << endl;
    cout << PSTR("  ,-'`'.   '._     \\") << endl;
    cout << PSTR(" /    .'  ___ `-._  dg|") << endl;
    cout << PSTR("|   .' ,-' __ `'/.`.'") << endl;
    cout << PSTR("\\ .' \\',-' 12 '-.  '.") << endl;
    cout << PSTR(" ` / / 11    7 1 `.  `.") << endl;
    cout << PSTR("  . '10     /    2 \\  ;") << endl;
    cout << PSTR("  | |      O      3|  |") << endl;
    cout << PSTR("  | |9      \\      '  '") << endl;
    cout << PSTR("  '  \\ 8     \\   4/  /") << endl;
    cout << PSTR("   '. `'.7  6  5.'  '") << endl;
    cout << PSTR("     `. _ `'''` _.'\\\\-.") << endl;
    cout << PSTR("      .//`''--''   (   )") << endl;
    cout << PSTR("     (   )          '-`") << endl;
    cout << PSTR("      `-'  ~ SunRiseClock ~") << endl << endl;
}
